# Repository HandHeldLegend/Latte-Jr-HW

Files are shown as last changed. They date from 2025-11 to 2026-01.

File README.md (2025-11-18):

# Latte Project
This is the official Github page for project Latte Jr from Hand Held Legend.

## Software and PCB License
<br />This firmware and PCB model are licensed under a <a rel="license" href="http://creativecommons.org/licenses/by-nc-sa/3.0/">Creative Commons Attribution-NonCommercial-ShareAlike 3.0 Unported License</a>.

## 3D Models License

<br />The 3D shell, buttons, and other associated models are licensed under a <a rel="license" href="http://creativecommons.org/licenses/by/4.0/">Creative Commons Attribution 4.0 International License</a>.

## Attributions

Resources Cross-Referenced for shell shape:
- 3D Scans by Wesk

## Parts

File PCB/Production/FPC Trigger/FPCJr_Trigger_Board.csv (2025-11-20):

Reference | Qty | Value | Datasheet | Footprint | Manufacturer | MPN | LCSC | DNP
C1,C2 | 2 | 100n | ~ | Capacitor_SMD:C_0201_0603Metric | muRata | GRM033R61A104KE15D | C76934
U1,U2 | 2 | HAL4395 | https://www.lcsc.com/datasheet/C49165022.pdf | Package_TO_SOT_SMD:SOT-23-5 | Hallwee | HAL4395SO5 | C49165022

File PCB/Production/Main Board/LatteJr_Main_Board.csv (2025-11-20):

Reference | Qty | Value | Datasheet | Footprint | Manufacturer | MPN | DNP | LCSC | Description
C1,C2,C6,C7 | 4 | 4.7u | ~ | Capacitor_SMD:C_0402_1005Metric | Samsung Electro-Mechanics | CL05A475KP5NRNC |  | C368809 | 10V 4.7uF X5R ±10% 0402 Ceramic Capacitors RoHS
C5,C8,C9,C10,C11,C12,C13,C14,C15,C16,C17,C18,C19,C28,C29,C30,C31,C32,C33,C34,C35 | 21 | 100n | ~ | Capacitor_SMD:C_0201_0603Metric | muRata | GRM033R61A104KE15D |  | C76934 | 10V 100nF X5R ±10% 0201 Ceramic Capacitors RoHS
J4,J5 | 2 | Conn_01x04_Pin | ~ | hhl:5051100492 | MOLEX | 5051100492 |  | C588007 | Generic connector, single row, 01x04, script generated
J6 | 1 | Conn_01x02_Socket | ~ | Connector_Molex:Molex_PicoBlade_53048-0210_1x02_P1.25mm_Horizontal | MOLEX | 530480210 |  | C505099 | Generic connector, single row, 01x02, script generated
L1 | 1 | 3.3u | https://abracon.com/datasheets/AOTA-B201610S3R3-101-T.pdf | hhl:L_pol_2016 | Abraco LLC | AOTA-B201610S3R3-101-T |  | C42411119 | 0806 POLARIZED Fixed Inductors RoHS
P1 | 1 | RPI-RM2 |  | hhl:RPI_RM2 | Raspberry Pi | RPI-RM2 |  | ~ | Raspberry Pi RM2 Wireless Module
R1 | 1 | 33 | ~ | Resistor_SMD:R_0201_0603Metric | YAGEO | RC0201FR-0733RL |  | C295794 | Resistor
SW1,SW2,SW3,SW4,SW5,SW6,SW7,SW8 | 8 | SW_Push | https://www.lcsc.com/datasheet/C221725.pdf | hhl:KSC-TE | C&K | KSC201J LFS |  | C221725 | Soft 160gf actuator, 3.5mm height tactile button IP67
SW9 | 1 | 1TS026A-1000-0550 | https://datasheet.lcsc.com/lcsc/2201131300_HYP--Hongyuan-Precision-1TS026A-1000-0550-CT_C913778.pdf | hhl:1TS026A-1000-0550 | HYP | 1TS026A-1000-0550 |  | C913778 | 50mA 2.6mm 100MΩ 200,000 Times 12V 100gf 1.6mm 0.55mm Round Button Standing paste SPST SMD,1.6x2.6mm Tactile Switches ROHS
U1 | 1 | RP2350_60QFN |  | hhl:RP2350-QFN-60-1EP_7x7_P0.4mm_EP3.4x3.4mm_ThermalVias | Raspberry Pi | RP2354A |  | C41378174 | QFN-60(7x7) Microcontrollers RoHS
U2,U3,U9,U10,U11,U12,U13,U14,U15,U16 | 10 | HAL4395 | https://www.lcsc.com/datasheet/C49165022.pdf | hhl:SOT-23-5L | Hallwee | HAL4395SO5 |  | C49165022 | SOT-23-5L Linear, Compass (ICs) ROHS
R2,R3,R4,R5,R31,R32,R33,R34,R35,R36 | 10 | 1k | ~ | Resistor_SMD:R_0201_0603Metric | YAGEO | RC0201FR-071KL |  | C138165 | 50mW Thick Film Resistors 25V ±1% ±200ppm/℃ 1kΩ,Resistor
C3,C4 | 2 | 15pF | ~ | Capacitor_SMD:C_0402_1005Metric | YAGEO | CC0402FRNPO9BN150 |  | C326803 | Unpolarized capacitor
C20,C22 | 2 | 1uF | ~ | Capacitor_SMD:C_0201_0603Metric | Murata Electronics | GRM033R60J105KEA2D |  | C76929 | 6.3V 1uF X5R ±10%
C21 | 1 | 0.47uF | https://www.lcsc.com/datasheet/C85926.pdf | Capacitor_SMD:C_0201_0603Metric | Murata Electronics | GRM033R60J474KE90D |  | C85926 | CAP CER 470nF 6.3V X5R 0201
C24 | 1 | 47uF | ~ | Capacitor_Tantalum_SMD:CP_EIA-3216-18_Kemet-A | Kyocera AVX | TAJA476K006RNJ |  | C7190 | 47uF 6.3V 1.6Ω@100kHz ±10%
C25,C27 | 2 | 10uF | ~ | Capacitor_SMD:C_0805_2012Metric | Samsung Electro-Mechanics | CL21A106KPFNNNE |  | C17024 | 10V 10uF X5R ±10%
C26 | 1 | 100nF | ~ | Capacitor_SMD:C_0201_0603Metric | Samsung Electro-Mechanics | CL03A104KQ3NNNC |  | C160831 | 6.3V 100nF X5R ±10%
D1,D3,D4 | 3 | CUS08F30,H3F | ${KIPRJMOD}/../progcc_v3_libs/docs/CUS08F30_datasheet_en_20140414.pdf | Diode_SMD:D_SOD-323_HandSoldering | TOSHIBA | CUS08F30,H3F |  | C150183 | SOD-323 Schottky Diodes ROHS (TOSHIBA)
IC1 | 1 | BQ27621YZFR-G1A | http://www.ti.com/lit/gpn/bq27621-g1 | hhl:BGA9C50P3X3_162X158X62 | Texas Instruments | BQ27621YZFR-G1A |  | C544417 | System-Side Fuel Gauge with Dynamic Voltage Correlation, Battery Gas Gauge
J3 | 1 | USB4056-03-A | https://www.mouser.jp/datasheet/2/837/usb4056-2448808.pdf | hhl:USB405603A | Global Connector Technology | USB4056-03-A |  | C7407280 | USB Connectors USB C 3.2 Rec, Horz, Hybrid PCB Top Mount, T+R
L2 | 1 | BLM18AG601SN1D | ~ | Inductor_SMD:L_0603_1608Metric | Murata Electronics | BLM18AG601SN1D |  | C19330 | Murata Electronics Ferrite Bead
L3 | 1 | 1.3A 2.2uH ±20% 80mΩ | ~ | Inductor_SMD:L_1008_2520Metric | INPAQ | MIP25202R2MBE |  | C315721 | 1.3A 2.2uH ±20% 80mΩ 1008 Inductors (SMD) ROHS
Q1,Q2 | 2 | BSS138DW | https://datasheet.lcsc.com/lcsc/1912111437_Diodes-Incorporated-BSS138DW-7-F_C154900.pdf | Package_TO_SOT_SMD:SOT-363_SC-70-6 | Diodes Incorporated | BSS138DW-7-F |  | C154900 | 50V 200mA 200mW 3.5Ω@10V,220mA 1.5V@250uA 2 N-Channel SC-70-6(SOT-363) MOSFETs ROHS
R6,R7 | 2 | 27R | ~ | Resistor_SMD:R_0201_0603Metric | YAGEO | RC0201FR-0727RL |  | C273268 | Resistor
R9,R10,R11,R12,R13,R14,R15,R16,R17,R18,R19,R20,R21,R22,R23,R30 | 16 | 100R | ~ | Resistor_SMD:R_0201_0603Metric | YAGEO | RC0201FR-07100RL |  | C77623 | 50mW Thick Film Resistors 25V ±1% ±200ppm/℃ 100Ω,Resistor
R24,R26,R27,R29 | 4 | 10k | ~ | Resistor_SMD:R_0201_0603Metric | YAGEO | RC0201FR-0710KL |  | C106225 | 50mW Thick Film Resistors 25V ±1% ±200ppm/℃ 10kΩ
R25 | 1 | 0R | ~ | Resistor_SMD:R_0201_0603Metric | YAGEO | RC0201FR-070RL |  | C106227 | 50mW Thick Film Resistors 25V ±1% 0Ω
R28 | 1 | 470R | ~ | Resistor_SMD:R_0201_0603Metric | YAGEO | AC0201FR-07470RL |  | C226558 | 50mW Thick Film Resistors ±1% ±200ppm/℃ 470Ω 0201 Chip Resistor - Surface Mount ROHS
R37,R38 | 2 | 5.1k | ~ | Resistor_SMD:R_0201_0603Metric | YAGEO | RC0201FR-075K1L |  | C274341 | 50mW Thick Film Resistors 25V ±1% ±200ppm/℃ 5.1kΩ
RGB1,RGB2,RGB3,RGB4,RGB5,RGB6,RGB7,RGB8,RGB9,RGB10,RGB11,RGB12,RGB13,RGB14 | 14 | SK6805-EC-10 | https://cdn-shop.adafruit.com/product-files/5849/SK6805-EC10-000_REV.01_EN.pdf | hhl:SK6805-EC-10 | OPSCO Optoelectronics | SK6805-EC-10 |  | C22394946 | RGB LED
U4 | 1 | TPS63001DRCR |  | hhl:VREG_V62_16624-01YE | Texas Instruments | TPS63001DRCR |  | C28060 | High efficiency Buck-Boost Converter with 1.8A Current Switches in 3x3 QFN
U5 | 1 | BQ25180 | https://www.ti.com/lit/ds/symlink/bq21061.pdf | hhl:DSBGA | Texas Instruments | BQ25180YBGR |  | C3682423 | 5.5V Lithium-ion/Polymer 1 1A DSBGA-8(1.1x1.6) Battery Management ROHS
U6,U7,U8 | 3 | USBLC6-2P6 | https://www.st.com/resource/en/datasheet/usblc6-2.pdf | Package_TO_SOT_SMD:SOT-666 | TECH PUBLIC | USBLC6-2P6 |  | C2827693 | Very low capacitance ESD protection diode, 2 data-line, SOT-666
Y1 | 1 | ABM8-272-T3 | ~ | Crystal:Crystal_SMD_3225-4Pin_3.2x2.5mm | Abracon LLC | ABM8-272-T3 |  | C20625731 | Four pin crystal, GND on pins 2 and 4

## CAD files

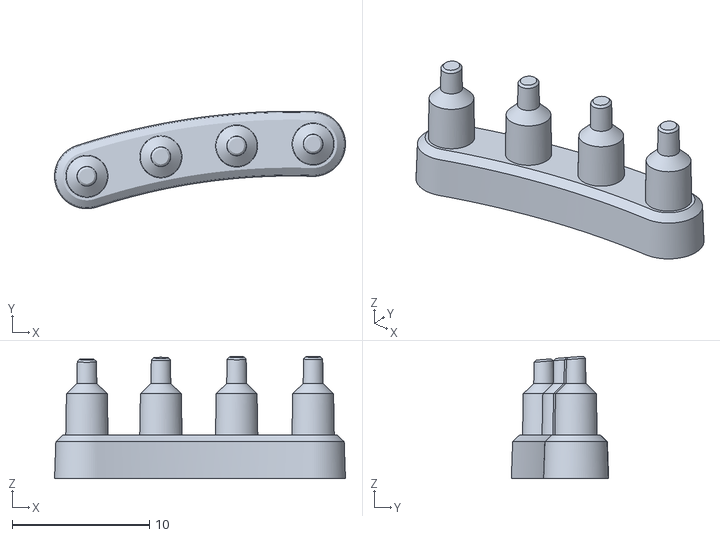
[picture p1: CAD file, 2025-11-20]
3D/STL/PLAYERLEDS.stl
21.2 x 7.10 x 8.93

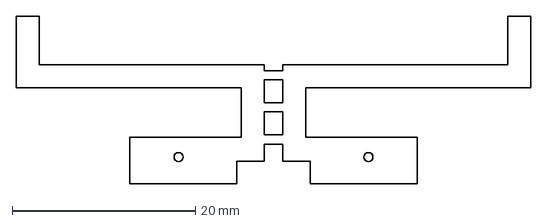
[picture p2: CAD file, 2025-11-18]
PCB/Projects/Trigger FPC/TriggerFPCJr.dxf
56.2 x 18.3 mm

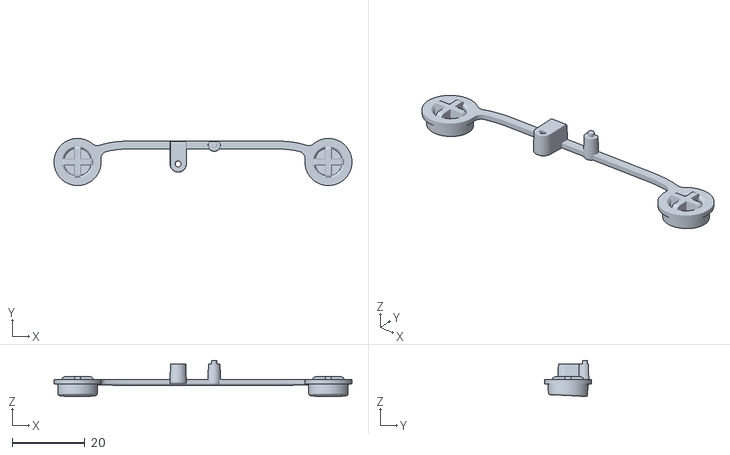
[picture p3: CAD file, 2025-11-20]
3D/STL/REARBUTTONS.stl
81.7 x 12.9 x 9.96

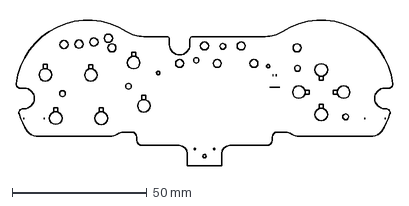
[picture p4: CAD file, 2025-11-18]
PCB/Projects/Main Board/PCBSKETCHEXPORT.dxf
140.1 x 55.4 mm

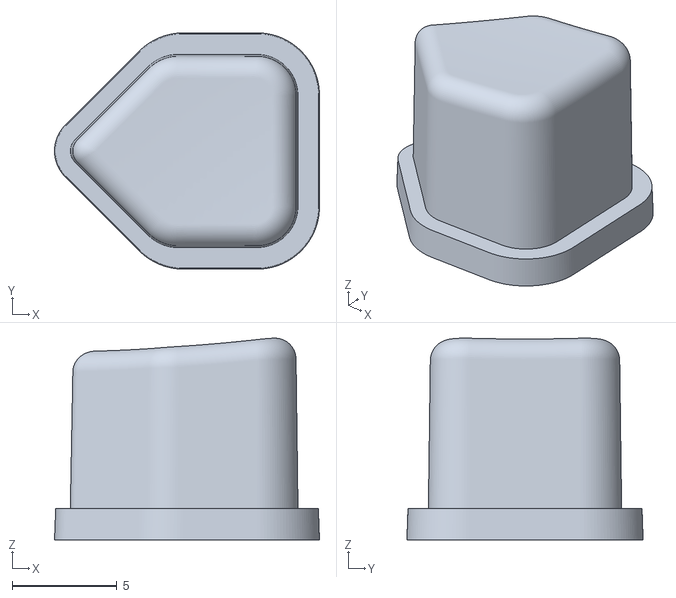
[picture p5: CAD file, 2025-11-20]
3D/STL/DPAD.stl
12.6 x 11.3 x 9.62

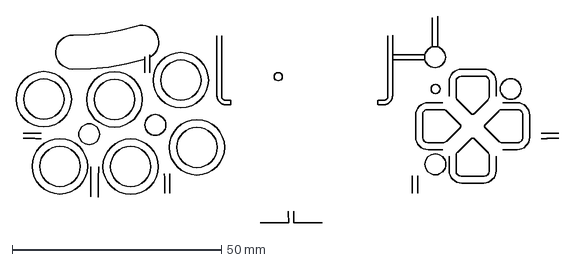
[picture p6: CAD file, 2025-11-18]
PCB/Projects/Main Board/PCB_TOP_KEEPOUT.dxf
129.8 x 49.4 mm

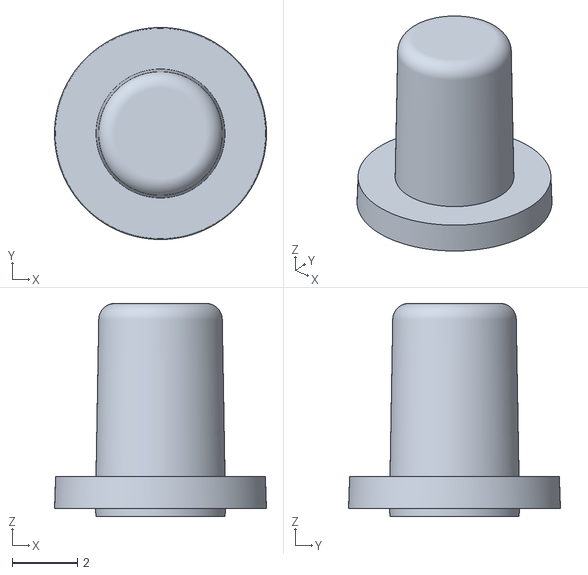
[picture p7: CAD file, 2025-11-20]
3D/STL/POWERBUTTON.stl
6.50 x 6.50 x 6.54

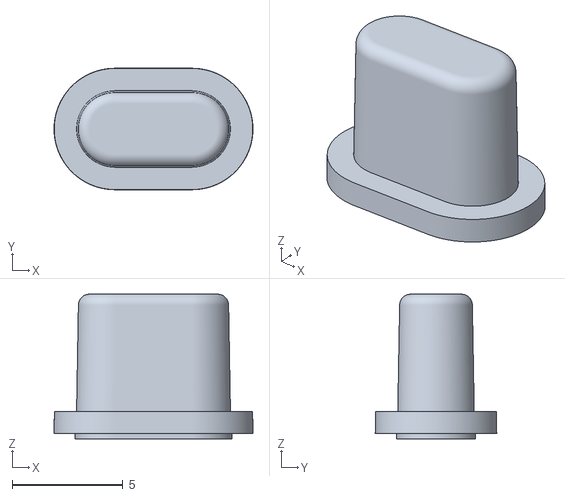
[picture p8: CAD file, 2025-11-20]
3D/STL/MENUBUTTON.stl
8.99 x 5.49 x 6.54

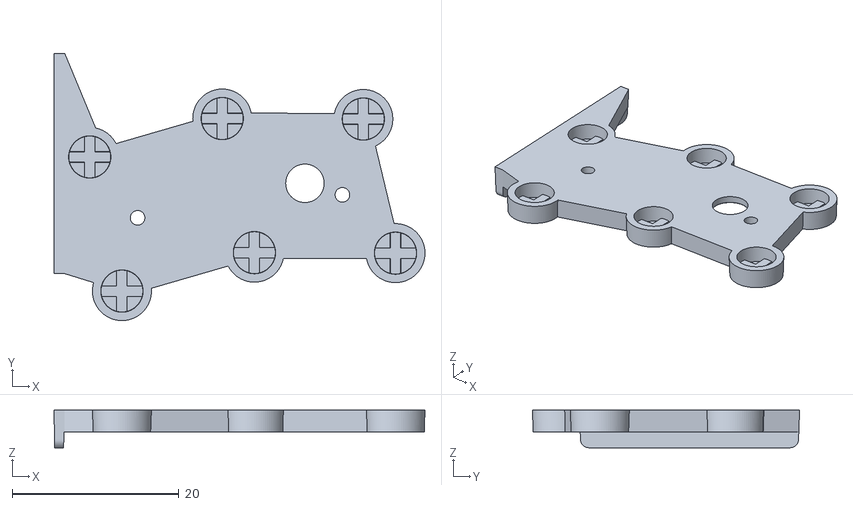
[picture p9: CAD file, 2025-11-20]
3D/STL/BRACKETBUTTONS.stl
44.4 x 32.0 x 4.50

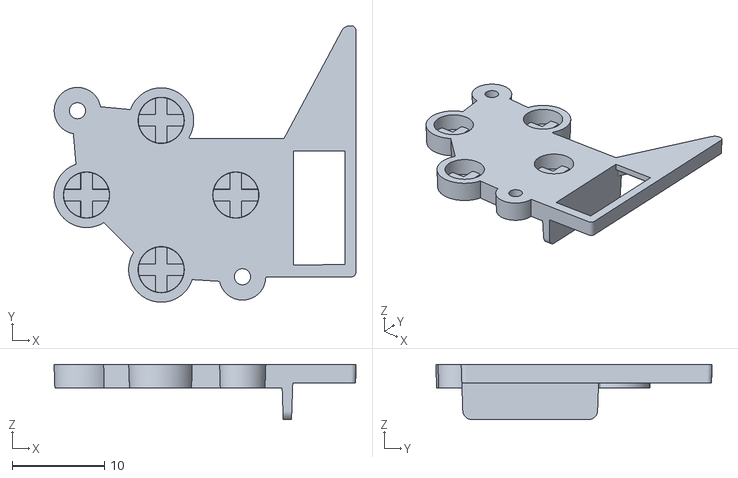
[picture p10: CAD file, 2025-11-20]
3D/STL/BRACKETDPAD.stl
32.8 x 30.0 x 6.00

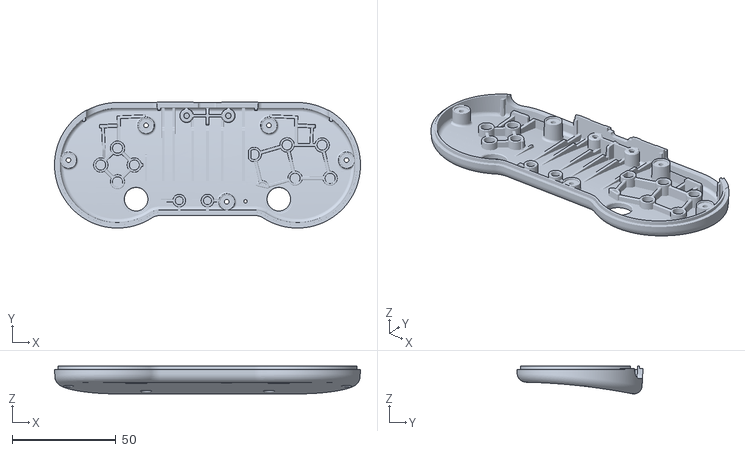
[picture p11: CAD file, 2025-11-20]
3D/STL/SHELLBOTTOM.stl
147.6 x 60.8 x 13.4

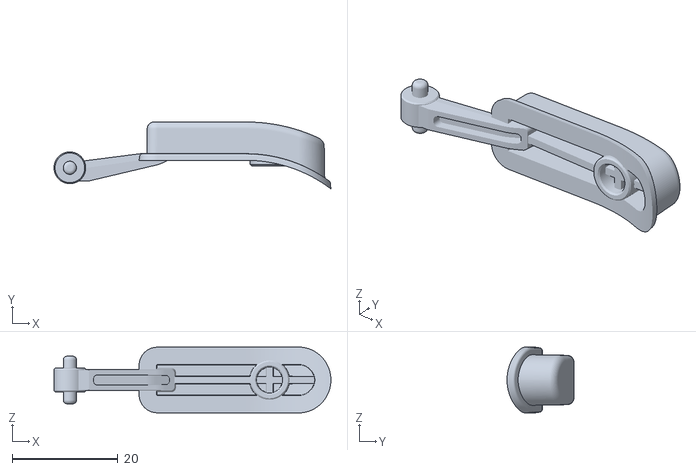
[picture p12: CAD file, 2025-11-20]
3D/STL/TRIGGER.stl
52.4 x 12.7 x 12.5

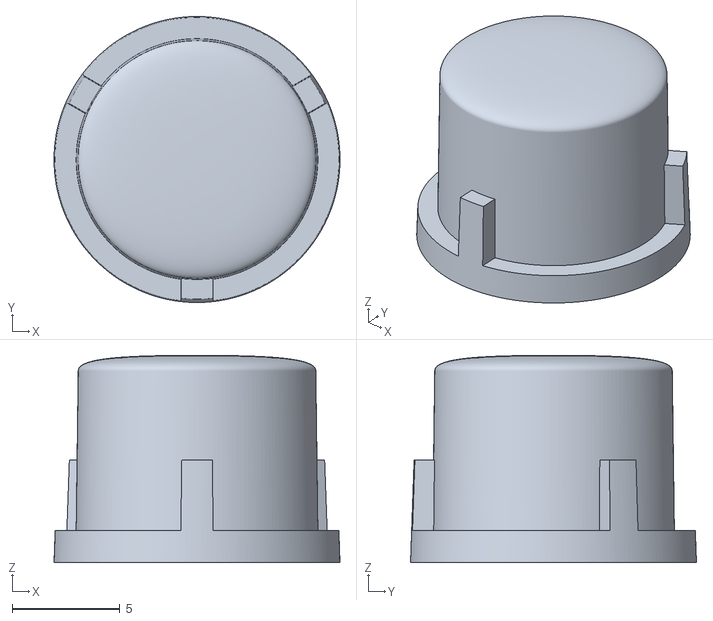
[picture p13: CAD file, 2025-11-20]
3D/STL/BUTTONPRIMARY.stl
13.3 x 13.3 x 9.61

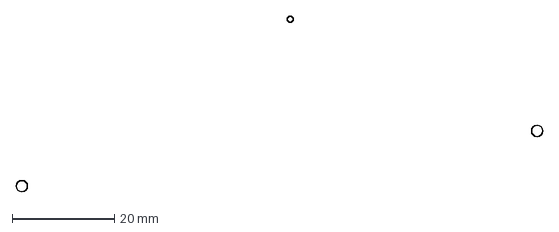
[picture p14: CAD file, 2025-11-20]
PCB/Projects/Main Board/PCB SCREW HOLE.dxf
103.0 x 34.3 mm

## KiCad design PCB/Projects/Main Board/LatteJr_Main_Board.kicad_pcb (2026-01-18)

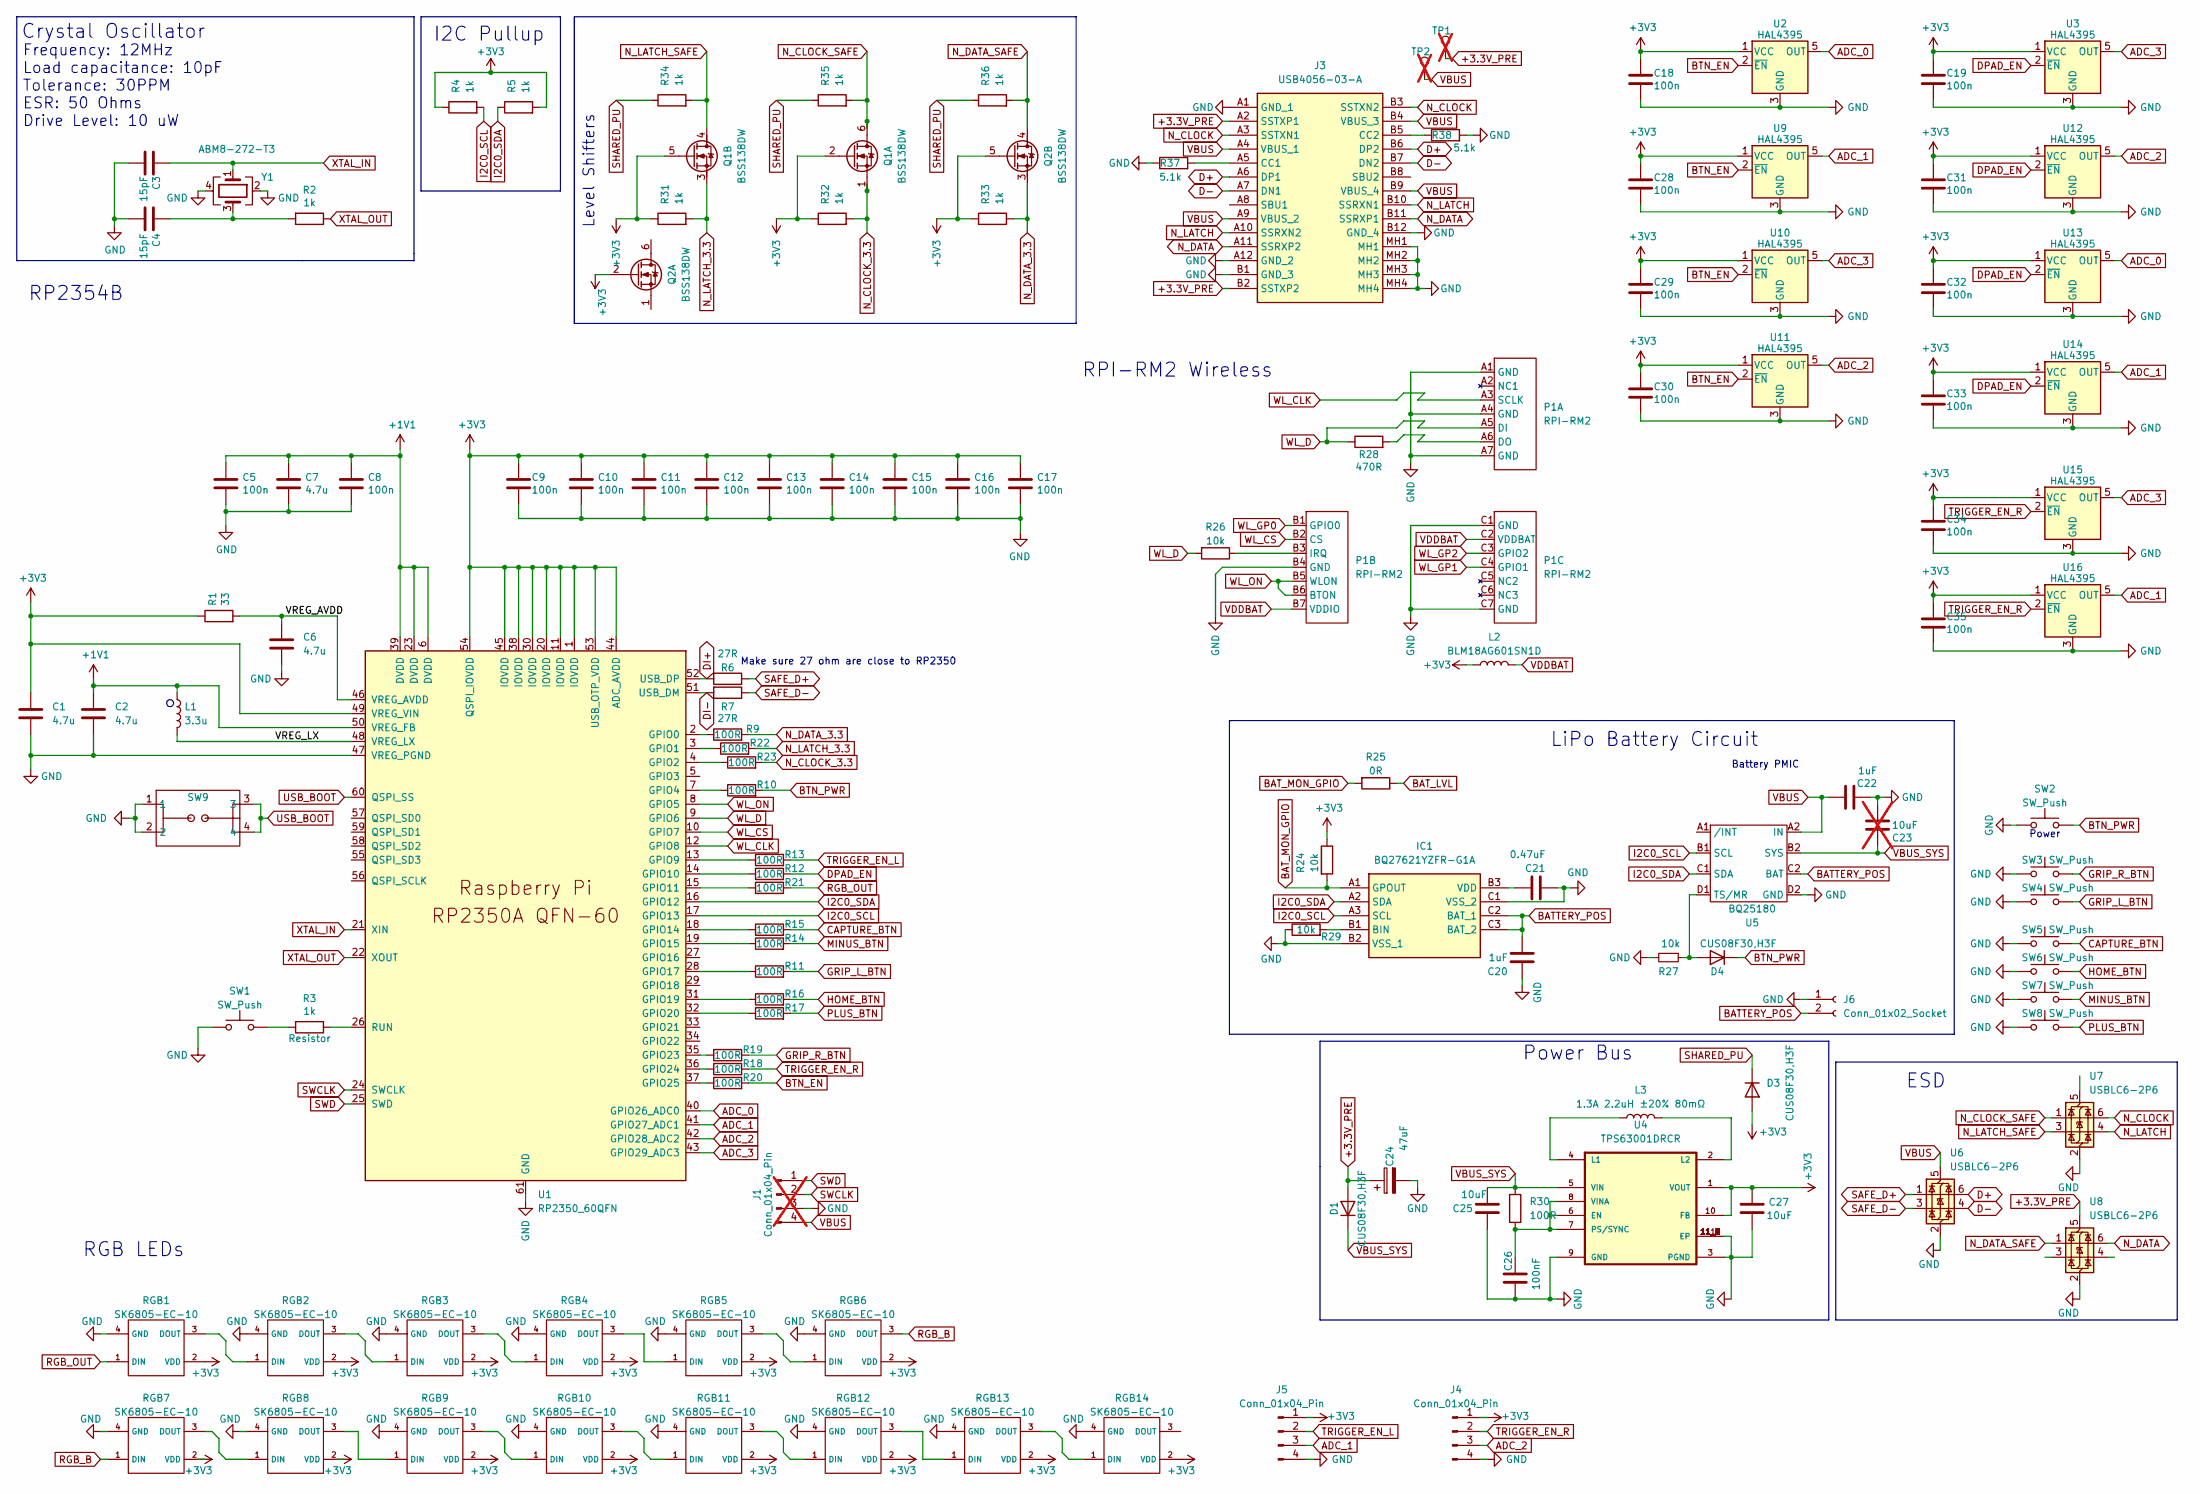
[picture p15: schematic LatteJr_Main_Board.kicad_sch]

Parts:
C1, C2, C6, C7: 4.7u; C_0402_1005Metric; MPN CL05A475KP5NRNC; LCSC C368809
C3, C4: 15pF; C_0402_1005Metric; MPN CC0402FRNPO9BN150; LCSC C326803
C5, C8, C9, C10, C11, C12, C13, C14, C15, C16, C17, C18, C19, C28, C29, C30, C31, C32, C33, C34, C35: 100n; C_0201_0603Metric; MPN GRM033R61A104KE15D; LCSC C76934
C20, C22: 1uF; C_0201_0603Metric; MPN GRM033R60J105KEA2D; LCSC C76929
C21: 0.47uF; C_0201_0603Metric; MPN GRM033R60J474KE90D; LCSC C85926
C23: 10uF; C_0805_2012Metric; MPN CL21A106KPFNNNE; LCSC C17024; not fitted
C24: 47uF; CP_EIA-3216-18_Kemet-A; MPN TAJA476K006RNJ; LCSC C7190
C25, C27: 10uF; C_0805_2012Metric; MPN CL21A106KPFNNNE; LCSC C17024
C26: 100nF; C_0201_0603Metric; MPN CL03A104KQ3NNNC; LCSC C160831
D1, D3, D4: CUS08F30,H3F; D_SOD-323_HandSoldering; MPN CUS08F30,H3F; LCSC C150183
IC1: BQ27621YZFR-G1A; BGA9C50P3X3_162X158X62; Mouser Part Number 595-BQ27621YZFR-G1A
J1: Conn_01x04_Pin; PinHeader_1x04_P2.00mm_Vertical; not fitted
J3: USB4056-03-A; USB405603A; Mouser Part Number 640-USB4056-03-A
J4, J5: Conn_01x04_Pin; 5051100492; MPN 5051100492; LCSC C588007
J6: Conn_01x02_Socket; Molex_PicoBlade_53048-0210_1x02_P1.25mm_Horizontal; MPN 530480210; LCSC C505099
L1: 3.3u; L_pol_2016; MPN AOTA-B201610S3R3-101-T; LCSC C42411119
L2: BLM18AG601SN1D; L_0603_1608Metric; MPN BLM18AG601SN1D; LCSC C19330
L3: 1.3A 2.2uH ±20% 80mΩ; L_1008_2520Metric; MPN MIP25202R2MBE; LCSC C315721
P1: RPI-RM2; RPI_RM2; MPN RPI-RM2
Q1, Q2: BSS138DW; SOT-363_SC-70-6; MPN BSS138DW-7-F; LCSC C154900
R1: 33; R_0201_0603Metric; MPN RC0201FR-0733RL; LCSC C295794
R2, R3, R4, R5, R31, R32, R33, R34, R35, R36: 1k; R_0201_0603Metric; MPN RC0201FR-071KL; LCSC C138165
R6, R7: 27R; R_0201_0603Metric; MPN RC0201FR-0727RL; LCSC C273268
R9, R10, R11, R12, R13, R14, R15, R16, R17, R18, R19, R20, R21, R22, R23, R30: 100R; R_0201_0603Metric; MPN RC0201FR-07100RL; LCSC C77623
R24, R26, R27, R29: 10k; R_0201_0603Metric; MPN RC0201FR-0710KL; LCSC C106225
R25: 0R; R_0201_0603Metric; MPN RC0201FR-070RL; LCSC C106227
R28: 470R; R_0201_0603Metric; MPN AC0201FR-07470RL; LCSC C226558
R37, R38: 5.1k; R_0201_0603Metric; MPN RC0201FR-075K1L; LCSC C274341
RGB1, RGB2, RGB3, RGB4, RGB5, RGB6, RGB7, RGB8, RGB9, RGB10, RGB11, RGB12, RGB13, RGB14: SK6805-EC-10; MPN SK6805-EC-10; LCSC C22394946
SW1, SW2, SW3, SW4, SW5, SW6, SW7, SW8: SW_Push; KSC-TE; MPN KSC201J LFS; LCSC C221725
SW9: 1TS026A-1000-0550; MPN 1TS026A-1000-0550; LCSC C913778
TP1, TP2: TestPoint; TestPoint_Pad_D1.0mm; not fitted
U1: RP2350_60QFN; RP2350-QFN-60-1EP_7x7_P0.4mm_EP3.4x3.4mm_ThermalVias; MPN RP2354A; LCSC C41378174
U2, U3, U9, U10, U11, U12, U13, U14, U15, U16: HAL4395; SOT-23-5L; MPN HAL4395SO5; LCSC C49165022
U4: TPS63001DRCR; VREG_V62_16624-01YE; MPN TPS63001DRCR; LCSC C28060
U5: BQ25180; DSBGA; MPN BQ25180YBGR; LCSC C3682423
U6, U7, U8: USBLC6-2P6; SOT-666; MPN USBLC6-2P6; LCSC C2827693
Y1: ABM8-272-T3; Crystal_SMD_3225-4Pin_3.2x2.5mm; MPN ABM8-272-T3; LCSC C20625731

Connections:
+1V1: C2.1, C5.1, C7.1, C8.1, L1.1, U1.6 (DVDD), U1.23 (DVDD), U1.39 (DVDD), U1.50 (VREG_FB)
+3.3V_PRE: C24.1, D1.2 (A), J3.A2 (SSTXP1), J3.B2 (SSTXP2), TP1.1, U8.5 (VBUS)
+3V3: C1.1, C9.1, C10.1, C11.1, C12.1, C13.1, C14.1, C15.1, C16.1, C17.1, C18.1, C19.1, C27.1, C28.1, C29.1, C30.1, C31.1, C32.1, C33.1, C34.1, C35.1, D3.2 (A), J4.1, J5.1, L2.1, Q1.2 (G1), Q1.5 (G2), Q2.2 (G1), Q2.5 (G2), R1.1, R4.1, R5.2, R24.1, R31.1, R32.1, R33.1, RGB1.2 (VDD), RGB2.2 (VDD), RGB3.2 (VDD), RGB4.2 (VDD), RGB5.2 (VDD), RGB6.2 (VDD), RGB7.2 (VDD), RGB8.2 (VDD), RGB9.2 (VDD), RGB10.2 (VDD), RGB11.2 (VDD), RGB12.2 (VDD), RGB13.2 (VDD), RGB14.2 (VDD), U1.1 (IOVDD), U1.11 (IOVDD), U1.20 (IOVDD), U1.30 (IOVDD), U1.38 (IOVDD), U1.44 (ADC_AVDD), U1.45 (IOVDD), U1.49 (VREG_VIN), U1.53 (USB_OTP_VDD), U1.54 (QSPI_IOVDD), U2.1 (VCC), U3.1 (VCC), U4.1 (VOUT), U4.10 (FB), U9.1 (VCC), U10.1 (VCC), U11.1 (VCC), U12.1 (VCC), U13.1 (VCC), U14.1 (VCC), U15.1 (VCC), U16.1 (VCC)
/VREG_AVDD: C6.1, R1.2, U1.46 (VREG_AVDD)
/VREG_LX: L1.2, U1.48 (VREG_LX)
ADC_0: U1.40 (GPIO26_ADC0), U2.5 (OUT), U13.5 (OUT)
ADC_1: J5.3, U1.41 (GPIO27_ADC1), U9.5 (OUT), U14.5 (OUT), U16.5 (OUT)
ADC_2: J4.3, U1.42 (GPIO28_ADC2), U11.5 (OUT), U12.5 (OUT)
ADC_3: U1.43 (GPIO29_ADC3), U3.5 (OUT), U10.5 (OUT), U15.5 (OUT)
BATTERY_POS: C20.2, IC1.C2 (BAT_1), IC1.C3 (BAT_2), J6.2, U5.C2 (BAT)
BAT_LVL: R25.1
BAT_MON_GPIO: IC1.A1 (GPOUT), R24.2, R25.2
BTN_EN: R20.2, U2.2 (~EN), U9.2 (~EN), U10.2 (~EN), U11.2 (~EN)
BTN_PWR: D4.1 (K), R10.2, SW2.2
CAPTURE_BTN: R15.2, SW5.2
D+: J3.A6 (DP1), J3.B6 (DP2), U6.6 (I/O1)
D-: J3.A7 (DN1), J3.B7 (DN2), U6.4 (I/O2)
DI+: R6.2, U1.52 (USB_DP)
DI-: R7.2, U1.51 (USB_DM)
DPAD_EN: R12.2, U3.2 (~EN), U12.2 (~EN), U13.2 (~EN), U14.2 (~EN)
GND: C1.2, C2.2, C3.2, C4.2, C5.2, C6.2, C7.2, C8.2, C9.2, C10.2, C11.2, C12.2, C13.2, C14.2, C15.2, C16.2, C17.2, C18.2, C19.2, C20.1, C21.2, C22.2, C23.1, C24.2, C25.1, C26.1, C27.2, C28.2, C29.2, C30.2, C31.2, C32.2, C33.2, C34.2, C35.2, IC1.B2 (VSS_1), IC1.C1 (VSS_2), J1.3, J3.A1 (GND_1), J3.A12 (GND_2), J3.B1 (GND_3), J3.B12 (GND_4), J3.MH1, J3.MH2, J3.MH3, J3.MH4, J4.4, J5.4, J6.1, P1.A1 (GND), P1.A4 (GND), P1.A7 (GND), P1.B4 (GND), P1.C1 (GND), P1.C7 (GND), R27.2, R29.1, R37.1, R38.2, RGB1.4 (GND), RGB2.4 (GND), RGB3.4 (GND), RGB4.4 (GND), RGB5.4 (GND), RGB6.4 (GND), RGB7.4 (GND), RGB8.4 (GND), RGB9.4 (GND), RGB10.4 (GND), RGB11.4 (GND), RGB12.4 (GND), RGB13.4 (GND), RGB14.4 (GND), SW1.1, SW2.1, SW3.1, SW4.1, SW5.1, SW6.1, SW7.1, SW8.1, SW9.1, SW9.2, U1.47 (VREG_PGND), U1.61 (GND), U2.3 (GND), U3.3 (GND), U4.3 (PGND), U4.9 (GND), U4.11 (EP), U4.11_1 (EP), U4.11_2 (EP), U4.11_3 (EP), U4.11_4 (EP), U4.11_5 (EP), U4.11_6 (EP), U4.11_7 (EP), U4.11_8 (EP), U5.D2 (GND), U6.2 (GND), U7.2 (GND), U8.2 (GND), U9.3 (GND), U10.3 (GND), U11.3 (GND), U12.3 (GND), U13.3 (GND), U14.3 (GND), U15.3 (GND), U16.3 (GND), Y1.2, Y1.4
GRIP_L_BTN: R11.2, SW4.2
GRIP_R_BTN: R19.2, SW3.2
HOME_BTN: R16.2, SW6.2
I2C0_SCL: IC1.A3 (SCL), R4.2, U1.17 (GPIO13), U5.B1 (SCL)
I2C0_SDA: IC1.A2 (SDA), R5.1, U1.16 (GPIO12), U5.C1 (SDA)
MINUS_BTN: R14.2, SW7.2
N_CLOCK: J3.A3 (SSTXN1), J3.B3 (SSTXN2), U7.6 (I/O1)
N_CLOCK_3.3: Q1.1 (S1), R23.2, R32.2
N_CLOCK_SAFE: Q1.6 (D1), R35.2, U7.1 (I/O1)
N_DATA: J3.A11 (SSRXP2), J3.B11 (SSRXP1), U8.6 (I/O1)
N_DATA_3.3: Q2.3 (D2), R9.2, R33.2
N_DATA_SAFE: Q2.4 (S2), R36.2, U8.1 (I/O1)
N_LATCH: J3.A10 (SSRXN2), J3.B10 (SSRXN1), U7.4 (I/O2)
N_LATCH_3.3: Q1.3 (D2), R22.2, R31.2
N_LATCH_SAFE: Q1.4 (S2), R34.2, U7.3 (I/O2)
unnamed: C4.1, R2.2, Y1.3
unnamed: D4.2 (A), R27.1, U5.D1 (TS/MR)
unnamed: IC1.B1 (BIN), R29.2
unnamed: C21.1, IC1.B3 (VDD)
unnamed: J3.A5 (CC1), R37.2
unnamed: J3.B5 (CC2), R38.1
unnamed: P1.A6 (DO), R28.2
unnamed: P1.B3 (IRQ), R26.1
unnamed: R3.2, SW1.2
unnamed: RGB1.3 (DOUT), RGB2.1 (DIN)
unnamed: RGB2.3 (DOUT), RGB3.1 (DIN)
unnamed: RGB3.3 (DOUT), RGB4.1 (DIN)
unnamed: RGB4.3 (DOUT), RGB5.1 (DIN)
unnamed: RGB5.3 (DOUT), RGB6.1 (DIN)
unnamed: RGB7.3 (DOUT), RGB8.1 (DIN)
unnamed: RGB8.3 (DOUT), RGB9.1 (DIN)
unnamed: RGB9.3 (DOUT), RGB10.1 (DIN)
unnamed: RGB10.3 (DOUT), RGB11.1 (DIN)
unnamed: RGB11.3 (DOUT), RGB12.1 (DIN)
unnamed: RGB12.3 (DOUT), RGB13.1 (DIN)
unnamed: RGB13.3 (DOUT), RGB14.1 (DIN)
unnamed: R9.1, U1.2 (GPIO0)
unnamed: R22.1, U1.3 (GPIO1)
unnamed: R23.1, U1.4 (GPIO2)
unnamed: R10.1, U1.7 (GPIO4)
unnamed: R13.1, U1.13 (GPIO9)
unnamed: R12.1, U1.14 (GPIO10)
unnamed: R21.1, U1.15 (GPIO11)
unnamed: R15.1, U1.18 (GPIO14)
unnamed: R14.1, U1.19 (GPIO15)
unnamed: R11.1, U1.28 (GPIO17)
unnamed: R16.1, U1.31 (GPIO19)
unnamed: R17.1, U1.32 (GPIO20)
unnamed: R19.1, U1.35 (GPIO23)
unnamed: R18.1, U1.36 (GPIO24)
unnamed: R20.1, U1.37 (GPIO25)
unnamed: R3.1, U1.26 (RUN)
unnamed: C26.2, R30.2, U4.6 (EN), U4.7 (PS/SYNC), U4.8 (VINA)
unnamed: L3.1, U4.4 (L1)
unnamed: L3.2, U4.2 (L2)
PLUS_BTN: R17.2, SW8.2
RGB_B: RGB6.3 (DOUT), RGB7.1 (DIN)
RGB_OUT: R21.2, RGB1.1 (DIN)
SAFE_D+: R6.1, U6.1 (I/O1)
SAFE_D-: R7.1, U6.3 (I/O2)
SHARED_PU: D3.1 (K), R34.1, R35.1, R36.1
SWCLK: J1.2, U1.24 (SWCLK)
SWD: J1.1, U1.25 (SWD)
TRIGGER_EN_L: J5.2, R13.2
TRIGGER_EN_R: J4.2, R18.2, U15.2 (~EN), U16.2 (~EN)
USB_BOOT: SW9.3, SW9.4, U1.60 (QSPI_SS)
VBUS: C22.1, J1.4, J3.A4 (VBUS_1), J3.A9 (VBUS_2), J3.B4 (VBUS_3), J3.B9 (VBUS_4), TP2.1, U5.A2 (IN), U6.5 (VBUS)
VBUS_SYS: C23.2, C25.2, D1.1 (K), R30.1, U4.5 (VIN), U5.B2 (SYS)
VDDBAT: L2.2, P1.B7 (VDDIO), P1.C2 (VDDBAT)
WL_CLK: P1.A3 (SCLK), U1.12 (GPIO8)
WL_CS: P1.B2 (CS), U1.10 (GPIO7)
WL_D: P1.A5 (DI), R26.2, R28.1, U1.9 (GPIO6)
WL_GP0: P1.B1 (GPIO0)
WL_GP1: P1.C4 (GPIO1)
WL_GP2: P1.C3 (GPIO2)
WL_ON: P1.B5 (WLON), P1.B6 (BTON), U1.8 (GPIO5)
XTAL_IN: C3.1, U1.21 (XIN), Y1.1
XTAL_OUT: R2.1, U1.22 (XOUT)

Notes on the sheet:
Power
ESD
RP2354B
RGB LEDs
RPI-RM2 Wireless
Crystal Oscillator
Level Shifters
I2C Pullup
Frequency: 12MHz Load capacitance: 10pF Tolerance: 30PPM ESR: 50 Ohms Drive Level: 10 uW
Power Bus
Make sure 27 ohm are close to RP2350
Battery PMIC
LiPo Battery Circuit

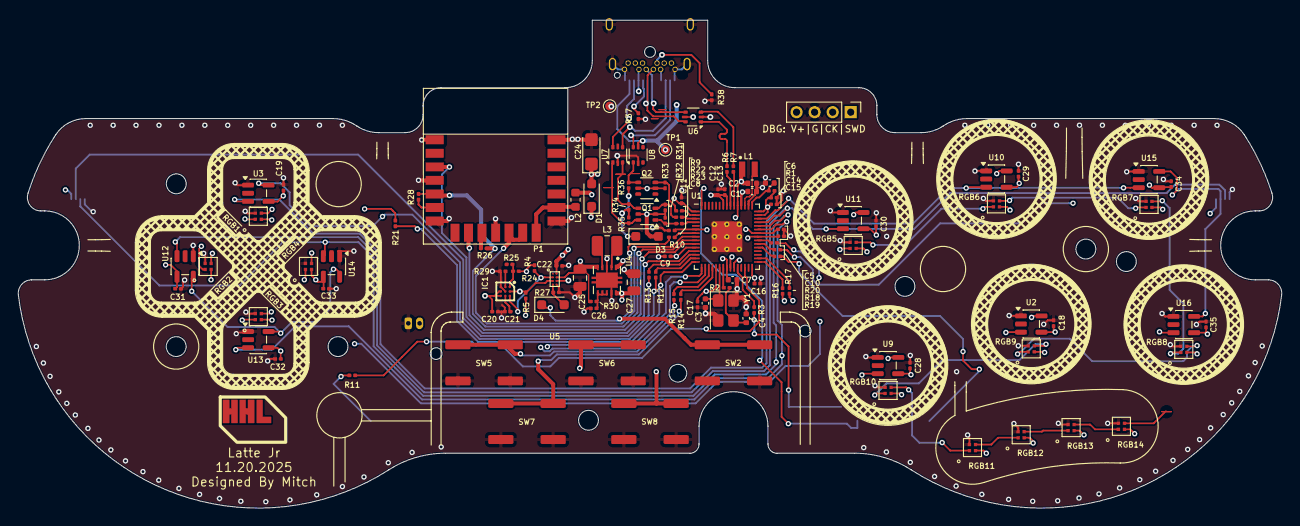
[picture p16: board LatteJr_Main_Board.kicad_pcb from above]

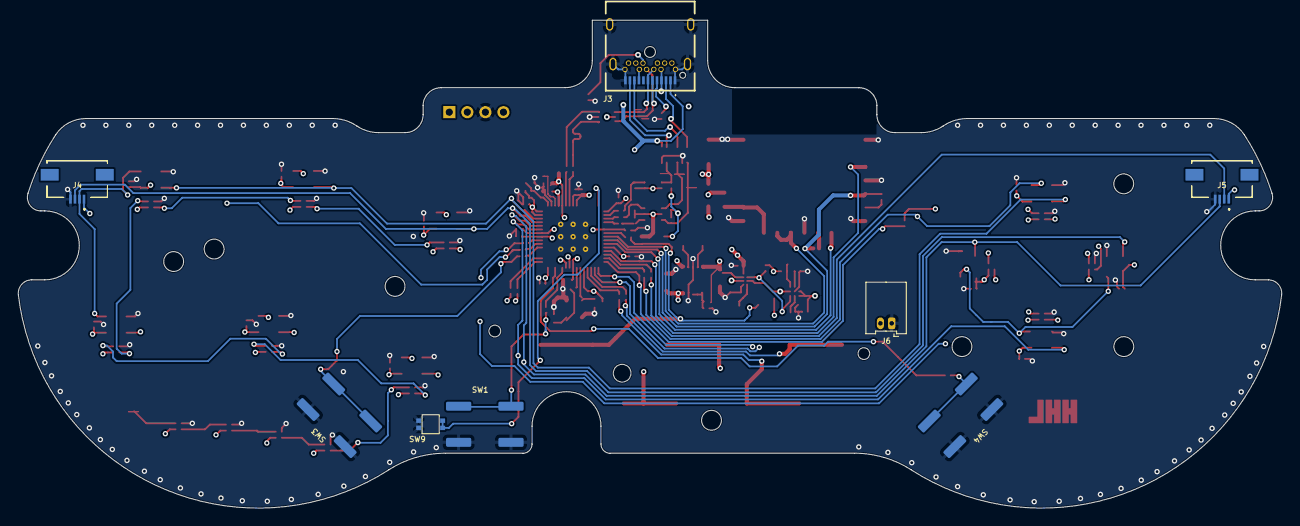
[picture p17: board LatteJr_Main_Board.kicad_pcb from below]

Board: 4 copper layers, 140.0 x 54.0 mm, 128 parts (8 on the bottom side), 95 nets.

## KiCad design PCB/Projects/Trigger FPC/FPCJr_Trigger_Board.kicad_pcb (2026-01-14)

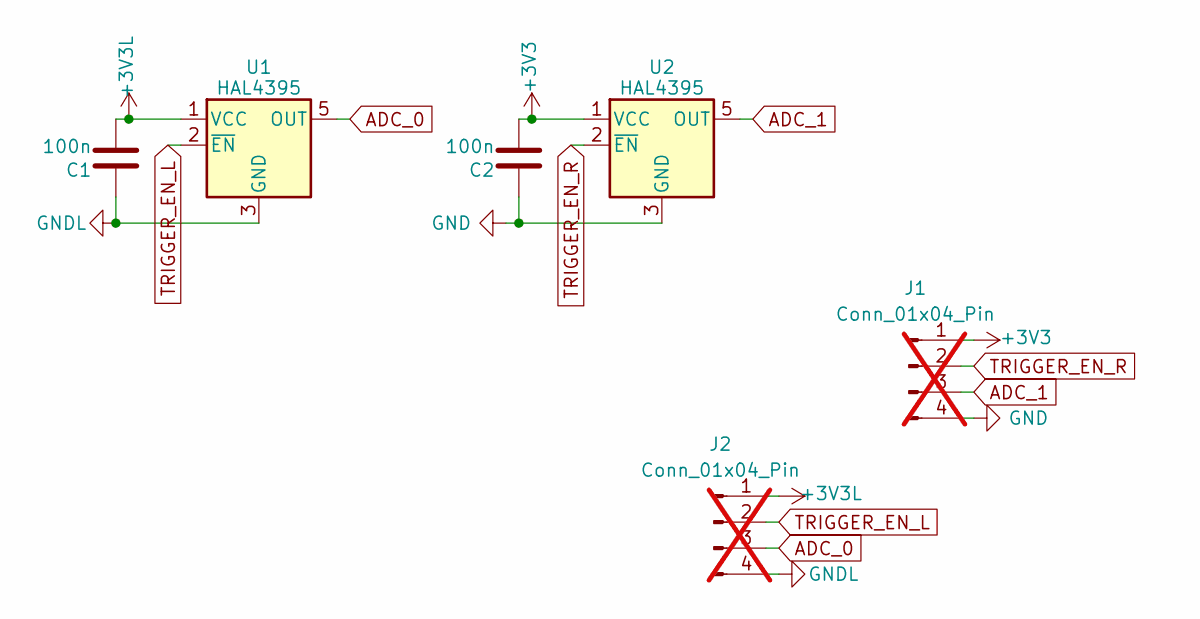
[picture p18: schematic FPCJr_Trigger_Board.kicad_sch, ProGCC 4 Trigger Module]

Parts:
C1, C2: 100n; C_0201_0603Metric; MPN GRM033R61A104KE15D; LCSC C76934
J1, J2: Conn_01x04_Pin; 505110-0492 Ribbon; not fitted
U1, U2: HAL4395; SOT-23-5L; MPN HAL4395SO5; LCSC C49165022

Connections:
+3V3: C2.2, J1.1, U2.1 (VCC)
+3V3L: C1.2, J2.1, U1.1 (VCC)
ADC_0: J2.3, U1.5 (OUT)
ADC_1: J1.3, U2.5 (OUT)
GND: C2.1, J1.4, U2.3 (GND)
GNDL: C1.1, J2.4, U1.3 (GND)
TRIGGER_EN_L: J2.2, U1.2 (~EN)
TRIGGER_EN_R: J1.2, U2.2 (~EN)

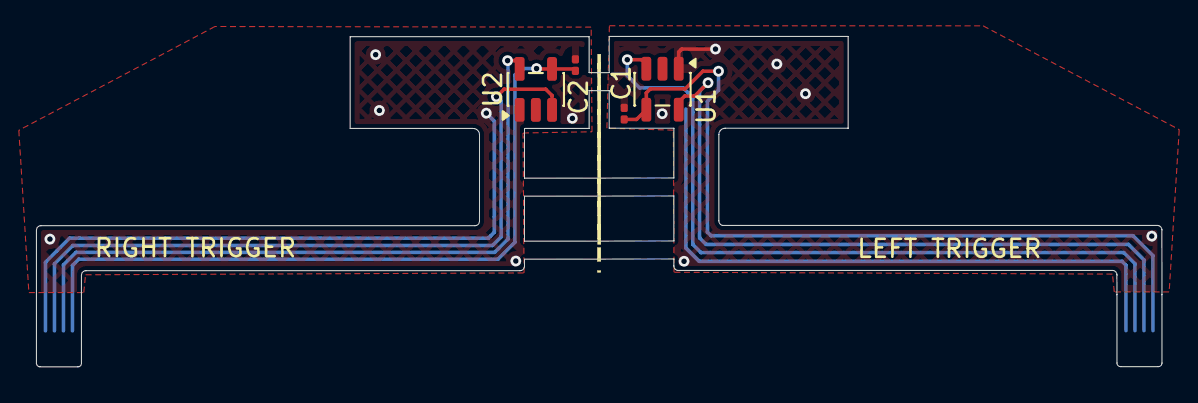
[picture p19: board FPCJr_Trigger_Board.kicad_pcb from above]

Board: 2 copper layers, 62.5 x 18.4 mm, 6 parts (0 on the bottom side), 8 nets.

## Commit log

2025-11-19 Some Routing
    [LatteJr_Main_Board.kicad_pcb, LatteJr_Main_Board.kicad_sch]
2025-11-19 Main Board Routing
    [LatteJr_Main_Board.kicad_pcb, LatteJr_Main_Board.kicad_sch]
2025-11-20 Update PCB
    [LatteJr_Main_Board.kicad_pcb, PCB SCREW HOLE.dxf]
2025-11-20 Flex PCB
    [FPCJr_Trigger_Board.kicad_pcb, FPCJr_Trigger_Board.kicad_sch]
2025-12-12 FPC fixes
    [FPCJr_Trigger_Board-B_Adhesive.gbr, FPCJr_Trigger_Board-B_Cu.gbr, FPCJr_Trigger_Board-B_Mask.gbr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]
2026-01-03 FPC Board Update
    [FPCJr_Trigger_Board.kicad_pcb]
2026-01-14 PCBs updated
    [FPCJr_Trigger_Board-B_Adhesive.gbr, FPCJr_Trigger_Board-B_Cu.gbr, FPCJr_Trigger_Board-B_Mask.gbr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]
2026-01-18 BOOT button placement
    [LatteJr_Main_Board.kicad_pcb]
